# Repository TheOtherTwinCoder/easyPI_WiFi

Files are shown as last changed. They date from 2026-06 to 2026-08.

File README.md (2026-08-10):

# easyPI_WiFi
Simply, a devboard with a WiFi shield using the RPI RM2, made for Macondo!

*Well, what's the point?*

I made easyPI WiFi for one simple reason - its customizability! Most custom board related to the Pi Pico don't have the ability to use shields (especially due to the lack of some pins, like pins 25 and 29) - which isn't great for adding features to your board (from just the regular features of a microcontroller!) 

Features:

- EVERY GPIO pin included with the RP2040 - such as pins 25 and 29 - while not losing out on other pins, like the ADC pins!
- RPI_RM2 compatibility with the shield, allowing for WiFi and Bluetooth
- USB-C rather than the normally used Micro-USB with Picos
- 264 KB of on-chip SRAM
- Software compatible with hundreds of distros and repos (mainly due to RP2040 support)
- All the features of a regular Pi Pico, too!

## How It Works
This'll be added once I build the PCB after reciving my parts!

## BOM
| Reference / Item | Package / Description | Qty | Value / Part | Source / Link | Cost (USD) |
|---|---|-----|---|---|---|
| C1, C10 | 0402 | 2 | 1uF | https://jlcpcb.com/partdetail/53938-CL05A105KA5NQNC/C52923 | |
| C11, C12, C17, C2, C3, C4, C5, C6, C7, C8, C9 | 0402 | 11 | 0.1uF | https://jlcpcb.com/partdetail/1877-CL05B104KO5NNNC/C1525 | |
| C13, C14 | 0402 | 2 | 10uF | https://jlcpcb.com/partdetail/16204-CL05A106MQ5NUNC/C15525 | |
| C15, C16 | 0402 | 2 | 33pF | https://jlcpcb.com/partdetail/1914-0402CG330J500NT/C1562 | |
| J1 | USB_C_Receptacle_HRO_TYPE-C-31-M-12 | 1 | USB-C Receptacle USB2.0 14P | https://jlcpcb.com/partdetail/Korean_HropartsElec-TYPE_C_31_M12/C165948 | |
| J2, J4 | PinHeader_1x20_P2.54mm_Vertical | 2 | Conn_01x20 | https://jlcpcb.com/partdetail/51993-2_54_1_20PStraightpin/C50981 | |
| J3 | PinHeader_1x03_P2.54mm_Vertical | 1 | 1x3 Header | https://jlcpcb.com/partdetail/25717-1_27_13PPin/C24980 | |
| J5 | PinHeader_1x01_P2.54mm_Vertical | 1 | Conn_01x01 | Not on LCSC | |
| R1, R2 | 0402 | 2 | 5.1kΩ | https://jlcpcb.com/partdetail/26648-0402WGF5101TCE/C25905 | |
| R3, R4 | 0402 | 2 | 27Ω | https://jlcpcb.com/partdetail/1445-RC02K360JT/C1093 | |
| R5, R7 | 0402 | 2 | 1kΩ | https://jlcpcb.com/partdetail/12256-0402WGF1001TCE/C11702 | |
| R6 | 0402 | 1 | 10kΩ | https://jlcpcb.com/partdetail/26274-0402WGJ0103TCE/C25531 | |
| SW1 | Alps SKRK Push Button | 1 | SPST-NO Push Switch | https://www.lcsc.com/product-detail/C2837531.html | |
| U1 | QFN-56-1EP 7x7mm P0.4mm EP3.2x3.2mm | 1 | RP2040 | https://jlcpcb.com/partdetail/LumbergAutomation-2040/C18129058 | |
| U2 | SOT-23 | 1 | MCP1700 Regulator | https://jlcpcb.com/partdetail/MicrochipTech-MCP1700_3302ETO/C511277 | |
| U3 | Winbond USON-8-1EP 3x2mm P0.5mm EP0.2x1.6mm | 1 | W25Q16JVSSIQ Flash Memory | https://jlcpcb.com/partdetail/WinbondElec-W25Q16JVSSIQ/C82317 | |
| Y1 | Crystal_SMD_3225-4Pin 3.2x2.5mm | 1 | 12 MHz Crystal | https://jlcpcb.com/partdetail/NDK-NX3225GA_12MHZ_STD_CRG2/C481407 | |
| LCSC Resistors (10kΩ + 470Ω) | Purchase | 1 | Components | LCSC | 1.55 |
| LCSC Shipping | Shipping | 1 | Shipping | LCSC | 9.01 |
| LCSC Handling Fee | Fee | 1 | Handling | LCSC | 3.00 |
| Amazon Socket Headers | Purchase | 1 | Socket Headers | Amazon | 8.81 |
| PiShop RM2 Module | Purchase | 1 | RM2 Module | PiShop | 4.40 |
| PiShop Shipping | Shipping | 1 | Shipping | PiShop | 6.76 |
| JLCPCB PCBs | Fabrication | 1 | PCB Order | JLCPCB | 5.12 |
| JLCPCB Shipping | Shipping | 1 | Shipping | JLCPCB | 66.03 |
| **TOTAL** |  |  |  |  | **105.13** |

## Images
Schematic for Main PCB:

Screenshot 2026-06-26 at 10 46 33 AM

PCB for Main PCB:

Screenshot 2026-08-03 at 5 08 48 PM

3D View for Main PCB: 

Screenshot 2026-06-26 at 10 47 35 AM

Schematic for WiFi Shield:

Screenshot 2026-06-26 at 10 48 29 AM

PCB for WiFi Shield:

Screenshot 2026-06-26 at 10 48 59 AM

3D View for WiFi Shield:

Screenshot 2026-06-26 at 10 49 33 AM

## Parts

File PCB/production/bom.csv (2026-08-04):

Designator | Footprint | Quantity | Value | LCSC Part #
C1, C10 | 0402 | 2 | 1uF
C11, C12, C17, C2, C3, C4, C5, C6, C7, C8, C9 | 0402 | 11 | 0.1uF
C13, C14 | 0402 | 2 | 10uF
C15, C16 | 0402 | 2 | 33pF
J1 | USB_C_Receptacle_HRO_TYPE-C-31-M-12 | 1 | USB_C_Receptacle_USB2.0_14P
J2, J4 | PinHeader_1x20_P2.54mm_Vertical | 2 | Conn_01x20
J3 | PinHeader_1x03_P2.54mm_Vertical | 1 | 1x3
J5 | PinHeader_1x01_P2.54mm_Vertical | 1 | Conn_01x01
R1, R2 | 0402 | 2 | 5.1K
R3, R4 | 0402 | 2 | 27
R5, R7 | 0402 | 2 | 1K
R6 | 0402 | 1 | 10K
SW1 | SW_Push_SPST_NO_Alps_SKRK | 1 | SW_Push
U1 | QFN-56-1EP_7x7mm_P0.4mm_EP3.2x3.2mm | 1 | 2040
U2 | SOT-23 | 1 | MCP
U3 | Winbond_USON-8-1EP_3x2mm_P0.5mm_EP0.2x1.6mm | 1 | Mem
Y1 | Crystal_SMD_3225-4Pin_3.2x2.5mm | 1 | 12 MHz

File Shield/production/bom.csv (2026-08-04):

Designator | Footprint | Quantity | Value | LCSC Part #
J1, J2 | PinSocket_1x03_P2.54mm_Vertical | 2 | Conn_01x03_Socket
J10, J11, J8, J9 | PinSocket_1x20_P2.54mm_Vertical | 4 | Conn_01x20_Socket
J3, J4 | PinSocket_1x01_P2.54mm_Vertical | 2 | Conn_01x01_Socket
R1 | 0805 | 1 | 470 OhM
R2 | 0805 | 1 | 10 kOhm
U1 | rpi_rmc20452t | 1 | RM2

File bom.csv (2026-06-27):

Designator | Footprint | Quantity | Value | LCSC Part #
C1, C10 | 0402 | 2 | 1uF | https://jlcpcb.com/partdetail/53938-CL05A105KA5NQNC/C52923
C11, C12, C17, C2, C3, C4, C5, C6, C7, C8, C9 | 0402 | 11 | 0.1uF | https://jlcpcb.com/partdetail/1877-CL05B104KO5NNNC/C1525
C13, C14 | 0402 | 2 | 10uF | https://jlcpcb.com/partdetail/16204-CL05A106MQ5NUNC/C15525
C15, C16 | 0402 | 2 | 33pF | https://jlcpcb.com/partdetail/1914-0402CG330J500NT/C1562
J1 | USB_C_Receptacle_HRO_TYPE-C-31-M-12 | 1 | USB_C_Receptacle_USB2.0_14P | https://jlcpcb.com/partdetail/Korean_HropartsElec-TYPE_C_31_M12/C165948
J2, J4 | PinHeader_1x20_P2.54mm_Vertical | 2 | Conn_01x20 | https://jlcpcb.com/partdetail/51993-2_54_1_20PStraightpin/C50981
J3 | PinHeader_1x03_P2.54mm_Vertical | 1 | 1x3 | https://jlcpcb.com/partdetail/25717-1_27_13PPin/C24980
J5 | PinHeader_1x01_P2.54mm_Vertical | 1 | Conn_01x01 | not on LCSC
R1, R2 | 0402 | 2 | 5.1K | https://jlcpcb.com/partdetail/26648-0402WGF5101TCE/C25905
R3, R4 | 0402 | 2 | 27 | https://jlcpcb.com/partdetail/1445-RC02K360JT/C1093
R5, R7 | 0402 | 2 | 1K | https://jlcpcb.com/partdetail/12256-0402WGF1001TCE/C11702
R6 | 0402 | 1 | 10K | https://jlcpcb.com/partdetail/26274-0402WGJ0103TCE/C25531
SW1 | SW_Push_SPST_NO_Alps_SKRK | 1 | SW_Push | https://www.lcsc.com/product-detail/C2837531.html
U1 | QFN-56-1EP_7x7mm_P0.4mm_EP3.2x3.2mm | 1 | 2040 | https://jlcpcb.com/partdetail/LumbergAutomation-2040/C18129058
U2 | SOT-23 | 1 | MCP | https://jlcpcb.com/partdetail/MicrochipTech-MCP1700_3302ETO/C511277
U3 | Winbond_USON-8-1EP_3x2mm_P0.5mm_EP0.2x1.6mm | 1 | Mem | https://jlcpcb.com/partdetail/WinbondElec-W25Q16JVSSIQ/C82317
Y1 | Crystal_SMD_3225-4Pin_3.2x2.5mm | 1 | 12 MHz | https://jlcpcb.com/partdetail/NDK-NX3225GA_12MHZ_STD_CRG2/C481407

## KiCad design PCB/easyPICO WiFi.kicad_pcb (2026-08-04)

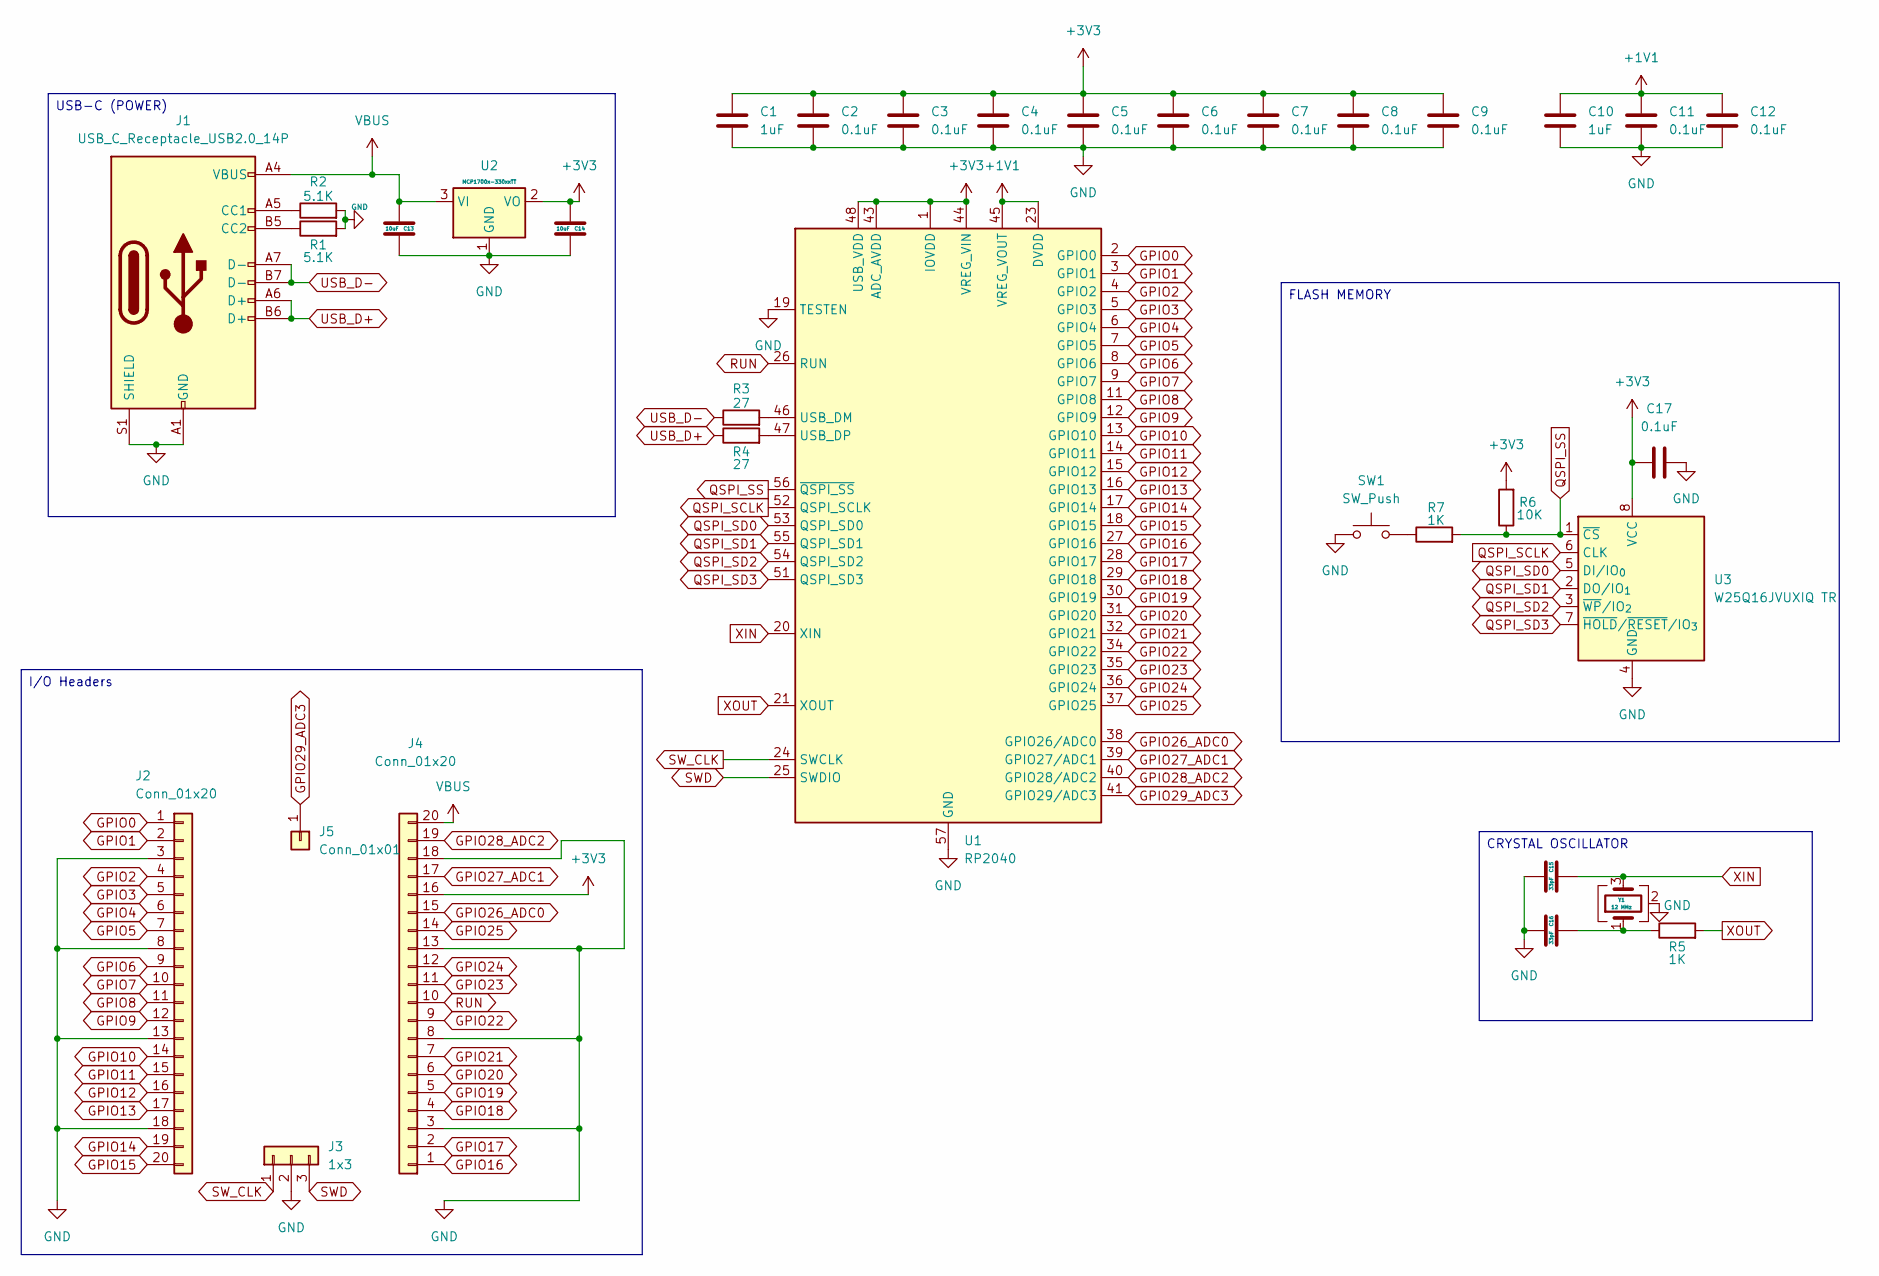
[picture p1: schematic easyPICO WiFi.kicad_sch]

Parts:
C1, C10: 1uF; C_0402_1005Metric
C2, C3, C4, C5, C6, C7, C8, C9, C11, C12, C17: 0.1uF; C_0402_1005Metric
C13, C14: 10uF; C_0402_1005Metric
C15, C16: 33pF; C_0402_1005Metric
J1: USB_C_Receptacle_USB2.0_14P; USB_C_Receptacle_HRO_TYPE-C-31-M-12
J2, J4: Conn_01x20; PinHeader_1x20_P2.54mm_Vertical
J3: 1x3; PinHeader_1x03_P2.54mm_Vertical
J5: Conn_01x01; PinHeader_1x01_P2.54mm_Vertical
R1, R2: 5.1K; R_0402_1005Metric
R3, R4: 27; R_0402_1005Metric
R5, R7: 1K; R_0402_1005Metric
R6: 10K; R_0402_1005Metric
SW1: SW_Push; SW_Push_SPST_NO_Alps_SKRK
U1: RP2040; QFN-56-1EP_7x7mm_P0.4mm_EP3.2x3.2mm
U2: MCP1700x-330xxTT; SOT-23
U3: W25Q16JVUXIQ TR; Winbond_USON-8-1EP_3x2mm_P0.5mm_EP0.2x1.6mm
Y1: 12 MHz; Crystal_SMD_3225-4Pin_3.2x2.5mm

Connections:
+1V1: C10.1, C11.1, C12.1, U1.23 (DVDD), U1.45 (VREG_VOUT), U1.50 (DVDD)
+3V3: C1.1, C2.1, C3.1, C4.1, C5.1, C6.1, C7.1, C8.1, C9.1, C14.1, C17.1, J4.16, R6.2, U1.1 (IOVDD), U1.10 (IOVDD), U1.22 (IOVDD), U1.33 (IOVDD), U1.42 (IOVDD), U1.43 (ADC_AVDD), U1.44 (VREG_VIN), U1.48 (USB_VDD), U1.49 (IOVDD), U2.2 (VO), U3.8 (VCC)
GND: C1.2, C2.2, C3.2, C4.2, C5.2, C6.2, C7.2, C8.2, C9.2, C10.2, C11.2, C12.2, C13.2, C14.2, C15.1, C16.1, C17.2, J1.A1 (GND), J1.A12 (GND), J1.B1 (GND), J1.B12 (GND), J1.S1 (SHIELD), J2.3, J2.8, J2.13, J2.18, J3.2, J4.3, J4.8, J4.13, J4.18, R1.2, R2.2, SW1.1, U1.19 (TESTEN), U1.57 (GND), U2.1 (GND), U3.4 (GND), Y1.2 (G), Y1.4 (G)
GPIO0: J2.1, U1.2 (GPIO0)
GPIO1: J2.2, U1.3 (GPIO1)
GPIO2: J2.4, U1.4 (GPIO2)
GPIO3: J2.5, U1.5 (GPIO3)
GPIO4: J2.6, U1.6 (GPIO4)
GPIO5: J2.7, U1.7 (GPIO5)
GPIO6: J2.9, U1.8 (GPIO6)
GPIO7: J2.10, U1.9 (GPIO7)
GPIO8: J2.11, U1.11 (GPIO8)
GPIO9: J2.12, U1.12 (GPIO9)
GPIO10: J2.14, U1.13 (GPIO10)
GPIO11: J2.15, U1.14 (GPIO11)
GPIO12: J2.16, U1.15 (GPIO12)
GPIO13: J2.17, U1.16 (GPIO13)
GPIO14: J2.19, U1.17 (GPIO14)
GPIO15: J2.20, U1.18 (GPIO15)
GPIO16: J4.1, U1.27 (GPIO16)
GPIO17: J4.2, U1.28 (GPIO17)
GPIO18: J4.4, U1.29 (GPIO18)
GPIO19: J4.5, U1.30 (GPIO19)
GPIO20: J4.6, U1.31 (GPIO20)
GPIO21: J4.7, U1.32 (GPIO21)
GPIO22: J4.9, U1.34 (GPIO22)
GPIO23: J4.11, U1.35 (GPIO23)
GPIO24: J4.12, U1.36 (GPIO24)
GPIO25: J4.14, U1.37 (GPIO25)
GPIO26_ADC0: J4.15, U1.38 (GPIO26/ADC0)
GPIO27_ADC1: J4.17, U1.39 (GPIO27/ADC1)
GPIO28_ADC2: J4.19, U1.40 (GPIO28/ADC2)
GPIO29_ADC3: J5.1, U1.41 (GPIO29/ADC3)
unnamed: C16.2, R5.1, Y1.1
unnamed: J1.A5 (CC1), R2.1
unnamed: J1.B5 (CC2), R1.1
unnamed: R7.1, SW1.2
unnamed: R3.2, U1.46 (USB_DM)
unnamed: R4.2, U1.47 (USB_DP)
QSPI_SCLK: U1.52 (QSPI_SCLK), U3.6 (CLK)
QSPI_SD0: U1.53 (QSPI_SD0), U3.5 (DI/IO_{0})
QSPI_SD1: U1.55 (QSPI_SD1), U3.2 (DO/IO_{1})
QSPI_SD2: U1.54 (QSPI_SD2), U3.3 (~WP/IO_{2})
QSPI_SD3: U1.51 (QSPI_SD3), U3.7 (~HOLD/~RESET/IO_{3})
QSPI_SS: R6.1, R7.2, U1.56 (~QSPI_SS), U3.1 (~CS)
RUN: J4.10, U1.26 (RUN)
SWD: J3.3, U1.25 (SWDIO)
SW_CLK: J3.1, U1.24 (SWCLK)
USB_D+: J1.A6 (D+), J1.B6 (D+), R4.1
USB_D-: J1.A7 (D-), J1.B7 (D-), R3.1
VBUS: C13.1, J1.A4 (VBUS), J1.A9 (VBUS), J1.B4 (VBUS), J1.B9 (VBUS), J4.20, U2.3 (VI)
XIN: C15.2, U1.20 (XIN), Y1.3
XOUT: R5.2, U1.21 (XOUT)

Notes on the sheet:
CRYSTAL OSCILLATOR
FLASH MEMORY
USB-C (POWER)
I/O Headers

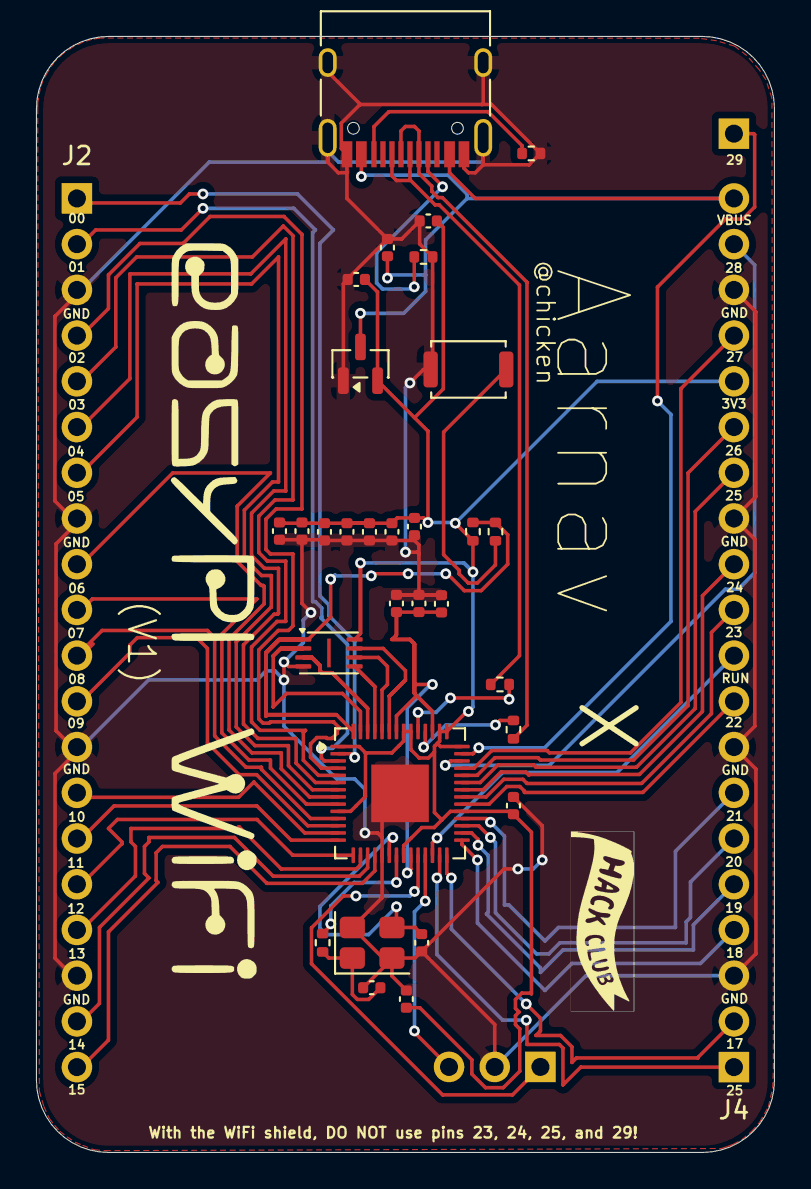
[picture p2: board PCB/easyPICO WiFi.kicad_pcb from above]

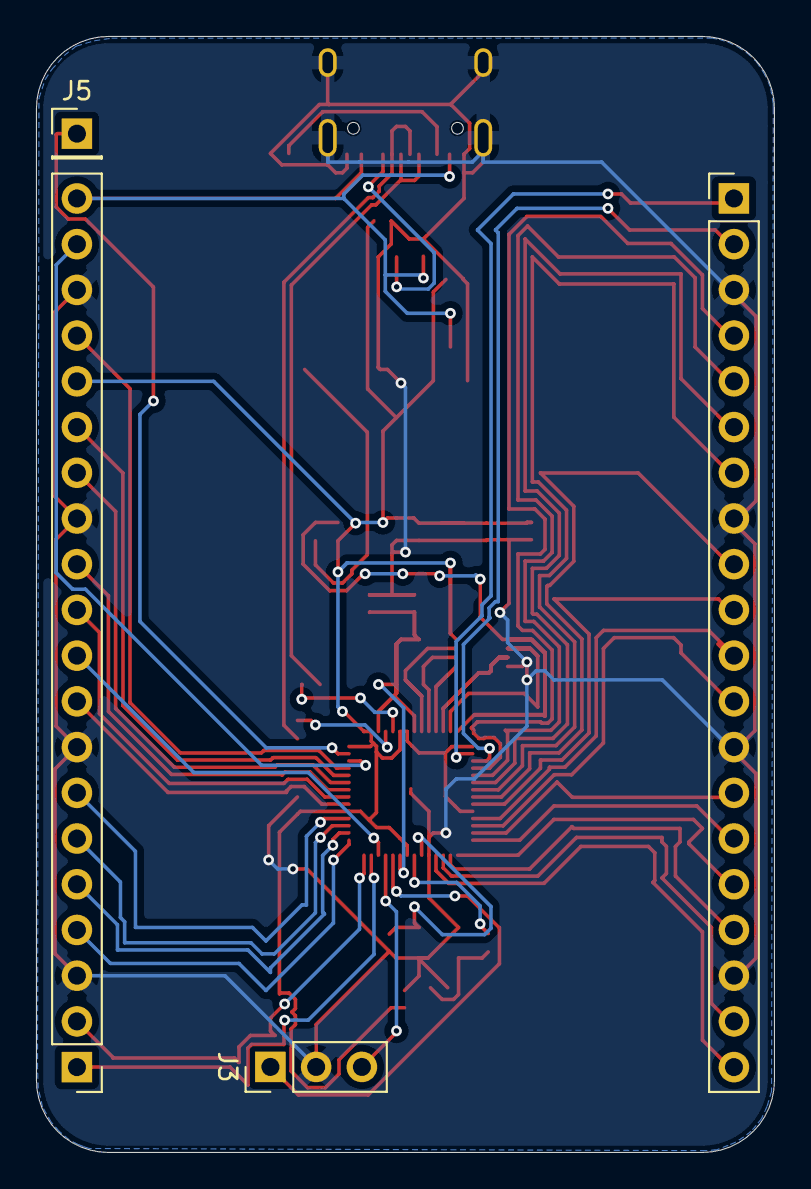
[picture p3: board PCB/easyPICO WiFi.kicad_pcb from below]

Board: 2 copper layers, 41.0 x 62.0 mm, 34 parts (4 on the bottom side), 53 nets.

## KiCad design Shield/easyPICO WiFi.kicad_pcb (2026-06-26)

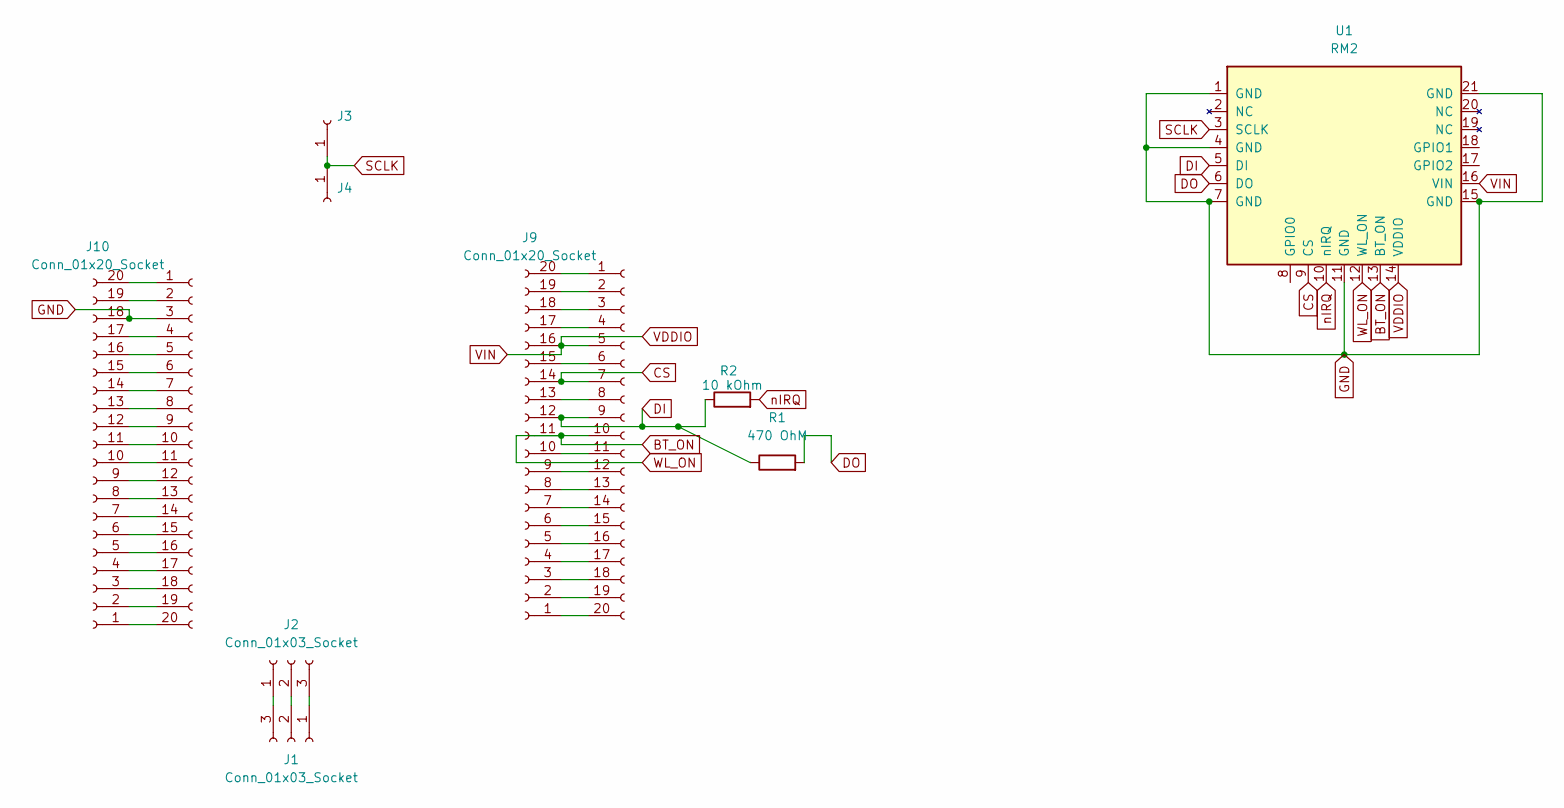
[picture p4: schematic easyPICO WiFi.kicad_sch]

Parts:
J1, J2: Conn_01x03_Socket; PinSocket_1x03_P2.54mm_Vertical
J3, J4: Conn_01x01_Socket; PinSocket_1x01_P2.54mm_Vertical
J8, J9, J10, J11: Conn_01x20_Socket; PinSocket_1x20_P2.54mm_Vertical
R1: 470 OhM; R_0805_2012Metric
R2: 10 kOhm; R_0805_2012Metric
U1: RM2; rpi_rmc20452t

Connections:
BT_ON: J8.10, J9.11, U1.12 (WL_ON), U1.13 (BT_ON)
CS: J8.7, J9.14, U1.9 (CS)
DI: J8.9, J9.12, R1.1, R2.1, U1.5 (DI)
DO: R1.2, U1.6 (DO)
GND: J10.18, J11.3, U1.1 (GND), U1.4 (GND), U1.7 (GND), U1.11 (GND), U1.15 (GND), U1.21 (GND)
unnamed: J1.1, J2.3
unnamed: J1.2, J2.2
unnamed: J1.3, J2.1
unnamed: J8.1, J9.20
unnamed: J8.2, J9.19
unnamed: J8.3, J9.18
unnamed: J8.4, J9.17
unnamed: J8.6, J9.15
unnamed: J8.8, J9.13
unnamed: J8.11, J9.10
unnamed: J8.12, J9.9
unnamed: J8.13, J9.8
unnamed: J8.14, J9.7
unnamed: J8.15, J9.6
unnamed: J8.16, J9.5
unnamed: J8.17, J9.4
unnamed: J8.18, J9.3
unnamed: J8.19, J9.2
unnamed: J8.20, J9.1
unnamed: J10.1, J11.20
unnamed: J10.2, J11.19
unnamed: J10.3, J11.18
unnamed: J10.4, J11.17
unnamed: J10.5, J11.16
unnamed: J10.6, J11.15
unnamed: J10.7, J11.14
unnamed: J10.8, J11.13
unnamed: J10.9, J11.12
unnamed: J10.10, J11.11
unnamed: J10.11, J11.10
unnamed: J10.12, J11.9
unnamed: J10.13, J11.8
unnamed: J10.14, J11.7
unnamed: J10.15, J11.6
unnamed: J10.16, J11.5
unnamed: J10.17, J11.4
unnamed: J10.19, J11.2
unnamed: J10.20, J11.1
SCLK: J3.1 (Pin_1_1), J4.1 (Pin_1_1), U1.3 (SCLK)
VDDIO: J8.5, J9.16, U1.14 (VDDIO), U1.16 (VIN)
nIRQ: R2.2, U1.10 (nIRQ)

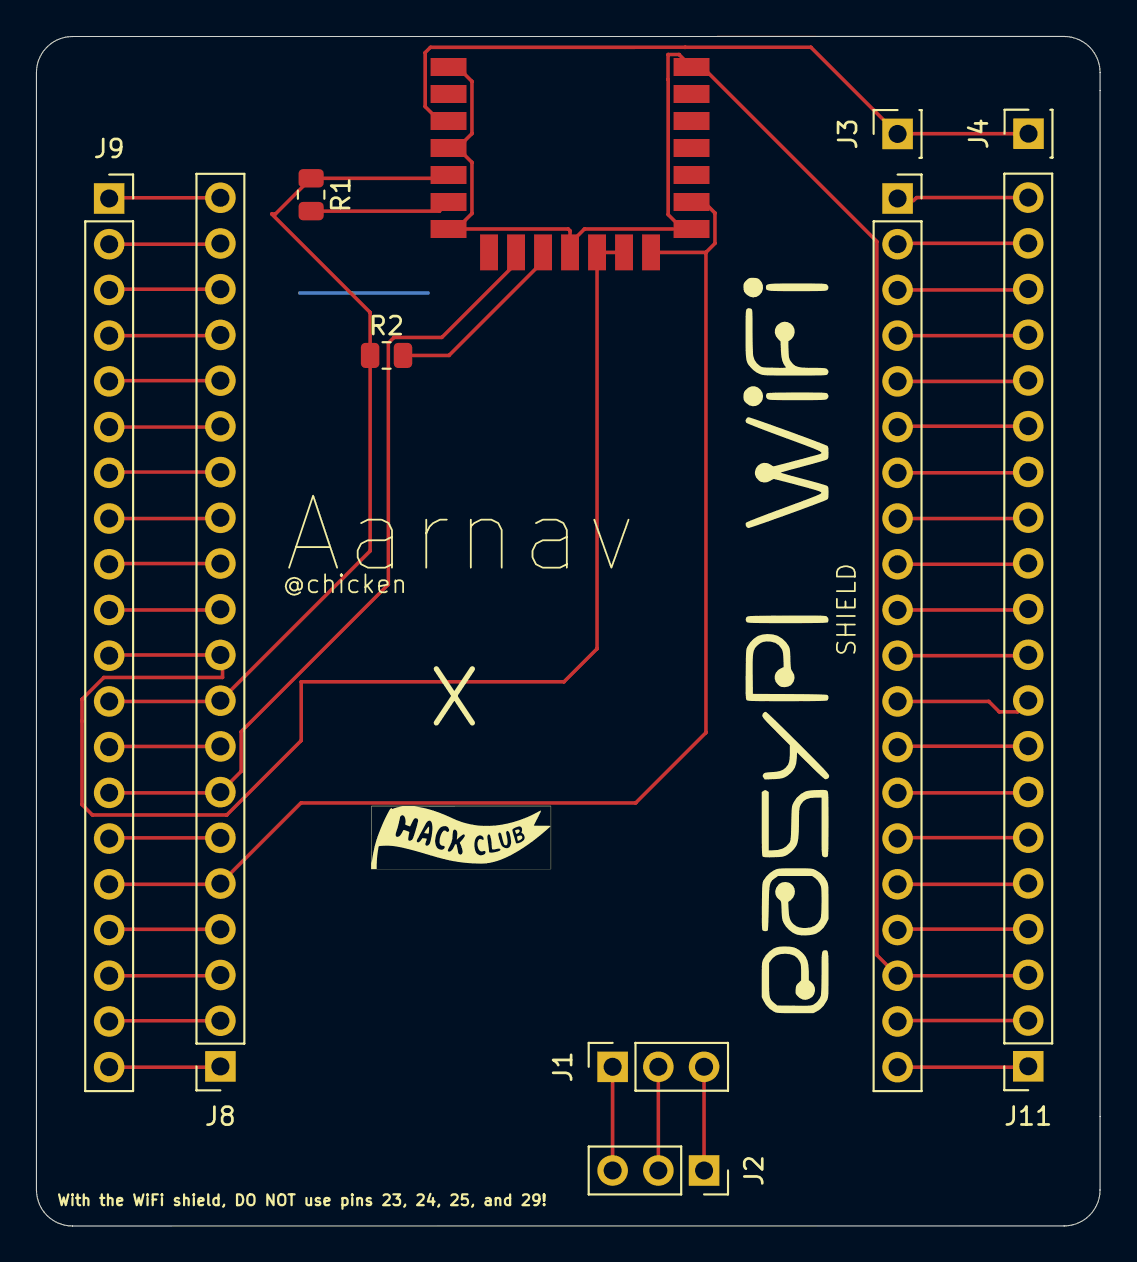
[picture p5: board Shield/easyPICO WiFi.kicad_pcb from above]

Board: 2 copper layers, 59.1 x 66.1 mm, 11 parts (0 on the bottom side), 46 nets.

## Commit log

2026-06-26 Add Updated Files
    [easyPICO WiFi.kicad_pcb]
2026-08-04 Removed all 90 degree traces + new image
2026-08-04 Fix gerber files + fix traces
    [bom.csv, designators.csv, positions.csv]
